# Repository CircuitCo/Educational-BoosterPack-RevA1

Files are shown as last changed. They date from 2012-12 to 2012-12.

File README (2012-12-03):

The Educational BoosterPack is an add-on board for the MSP430 Value Line LaunchPad development kit. This BoosterPack will help new users familiar with the MSP430 LaunchPad by interacting with simple electronic components like LEDs (red/green/blue and white), analog potentiometer, microphone, and speaker. Users will also be able to create more exciting projects with the onboard analog accelerometer and 2x16 character LCD.

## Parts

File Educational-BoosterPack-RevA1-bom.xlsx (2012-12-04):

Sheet: EDUCATIONALBOOSTERPACK
EDUCATIONAL BOOSTERPACK |  |  |  | Revised: | 2012-12-03
BP-EDUC-01 Revision: A1
ITM | QTY | REF DESIGNATOR | PART | PCB FOOTPRINT | DESCRIPTION | MANU | MANU P/N | VENDOR | VENFOR P/N
1 | 5 | C3,C6,C7,C8,C9 | 0.1uF | 402 | CAP CER 0.1UF 10V 10% X5R 0402 | TAIYO | LMK105BJ104KV-F | DK | 587-1227-1-ND
2 | 3 | C4,C11,C12 | 1uF | 402 | CAP CER 1UF 6.3V 10% X5R 0402 | TAIYO | JMK105BJ105KV-F | DK | 587-1231-1-ND
3 | 1 | C5 | 10nF | 402 | CAP CER 10000PF 16V 10% X7R 0402 | YAGEO | CC0402KRX7R7BB103 | DK | 311-1042-1-ND
4 | 1 | C10 | 4.7uF | 603 | CAP CER 4.7UF 6.3V 20% X5R 0603 | MURATA | GRM188R60J475ME19D | DK | 490-5421-1-ND
5 | 1 | D4 | SMW-CL25 | LED603 | LED CHIPLED INGAN WHT TOP SMD | AVAGO | HSMW-CL25 | DK | 516-2278-1-ND
6 | 1 | D6 | CLV6A-FKB | TRICOLOR | LED RED/GREEN/BLUE PLCC6 SMD | CREE | CLV6A-FKB-CK1P1G1BB7R3R3 | DK | CLV6A-FKB-CK1P1G1BB7R3R3CT-ND
7 | 2 | J1,J2 | 1X10 | HEADER1X10 | CONN HEADER FMALE 10POS .1" GOLD | SULLINS | PPPC101LFBN-RC | DK | S7043-ND
8 | 0 | J3,J4 | 1X10,DNI | HEADER1X10 | CONN HEADER FMALE 10POS .1" GOLD | SULLINS | PPPC101LFBN-RC | DK | S7043-ND
9 | 2 | J5,J6 | 1X03 | HEADER1X03 | CONN HEADER .100 SINGL STR 3POS | SULLINS | PEC03SAAN | DK | S1012E-03-ND
10 | 1 | LCD1 | NHD-C0216CZ | LCD | LCD COG CHAR 2X16 WHT TRANSFL | NEWHAVEN | NHD-C0216CZ-FSW-FBW-3V3 | DK | NHD-C0216CZ-FSW-FBW-3V3-ND
11 | 1 | MIC1 | CMC-5042PF-AC | MIC | MIC COND ANALOG OMNI -42DB | CUI | CMC-5042PF-AC | DK | 102-1724-ND
12 | 2 | MK1,MK2 | GATOR | GATOR | GATOR HOLES | N/A | N/A | N/A | N/A
13 | 1 | Q1 | BSS138 | SOT23-3 | MOSFET N-CH 50V 200MA SOT23-3 | DIODES | BSS138-7-F | DK | BSS138-FDICT-ND
14 | 1 | R1 | 33 | 402 | RES 33 OHM 1/16W 5% 0402 SMD | YAGEO | RC0402JR-0733RL | DK | 311-33JRCT-ND
15 | 2 | R2,R9 | 2.2K | 402 | RES 2.2K OHM 1/16W 5% 0402 SMD | VISHAY | CRCW04022K20JNED | DK | 541-2.2KJCT-ND
16 | 1 | R5 | 150 | 402 | RES 150 OHM 1/16W 5% 0402 SMD | YAGEO | RC0402JR-07150RL | DK | 311-150JRCT-ND
17 | 2 | R6,R7 | 100 | 402 | RES 100 OHM 1/16W 5% 0402 SMD | YAGEO | RC0402JR-07100RL | DK | 311-100JRCT-ND
18 | 1 | R8 | 180R, 5% | 402 | RES 180 OHM 1/16W 5% 0402 SMD | YAGEO | RC0402JR-07180RL | DK | 311-180JRCT-ND
19 | 1 | R10 | 100K | 402 | RES 100K OHM 1/16W 5% 0402 SMD | VISHAY | CRCW0402100KJNED | DK | 541-100KJCT-ND
20 | 1 | R11 | 47K | 402 | RES 47K OHM 1/16W 5% 0402 SMD | VISHAY | CRCW040247K0JNED | DK | 541-47KJCT-ND
21 | 1 | R12 | 15R, 0603 | 603 | RES 15 OHM .25W 5% 0603 SMD | VISHAY | CRCW060315R0JNEAHP | DK | CRCW060315R0JNEAHPCT-ND
22 | 2 | R14,R19 | 10K | 402 | RES 10K OHM 1/16W 5% 0402 SMD | VISHAY | CRCW040210K0JNED | DK | 541-10KJCT-ND
23 | 1 | R15 | 1K,0603 | 603 | RES 1.0K OHM 1/10W 5% 0603 SMD | VISHAY | CRCW06031K00JNEA | DK | 541-1.0KGCT-ND
24 | 1 | R17 | 22M,0603 | 603 | RES 22M OHM 1/10W 10% 0603 SMD | PANASONIC | ERJ-3GEYK226V | DK | P22MGCT-ND
25 | 2 | SH1,SH2 | SHUNT | SHUNT | CONN JUMPER SHORTING GOLD FLASH | SULLINS | SPC02SYAN | DK | S9001-ND
26 | 1 | SPKR1 | BUZZER | BUZZER | BUZZER 2.048KHZ 12MM PC MOUNT | CUI | CEM-1203(42) | DK | 102-1153-ND
27 | 1 | TP1 | TESTPOINT | TP | TESTPOINT HOLE | N/A | N/A | N/A | N/A
28 | 1 | U1 | ADXL335 | 16LFCSP | IC ACCELEROMETER 3AXL 3G 16LFCSP | ANALOG | ADXL335BCPZ-RL7 | DK | ADXL335BCPZ-RL7CT-ND
29 | 1 | VR1 | 10K,20% | POT | POT 10K OHM THUMBWHEEL CERM ST | BOURNS | 3352T-1-103LF | DK | 3352T-103LF-ND
30 | 1 | PCB

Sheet: CHANGES
DATE | REV | CHANGES
2012-11-19 | A1 | CHANGE P/N FOR VR1 FROM SM-43 TO 3352T-1-103LF
 |  | REMOVE D5
 |  | REMOVE R13
 |  | CHANGE R9 VALUE FROM 4.7K TO 2.2K
 |  | REMOVE D1, D2, D3
 |  | ADD D6
 |  | ADD R15
 |  | ADD MK1
2012-11-20 |  | ADD MK2
 |  | ADD TP1
 |  | ADD R17
 |  | ADD J5,J6
 |  | ADD R19
 |  | CHANGE R14 VALUE

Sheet: ASSY INSTRUCTIONS
USE SHUNT JUMPERS TO CONNECT J5.1-J5.2 AND J6.1-J6.2

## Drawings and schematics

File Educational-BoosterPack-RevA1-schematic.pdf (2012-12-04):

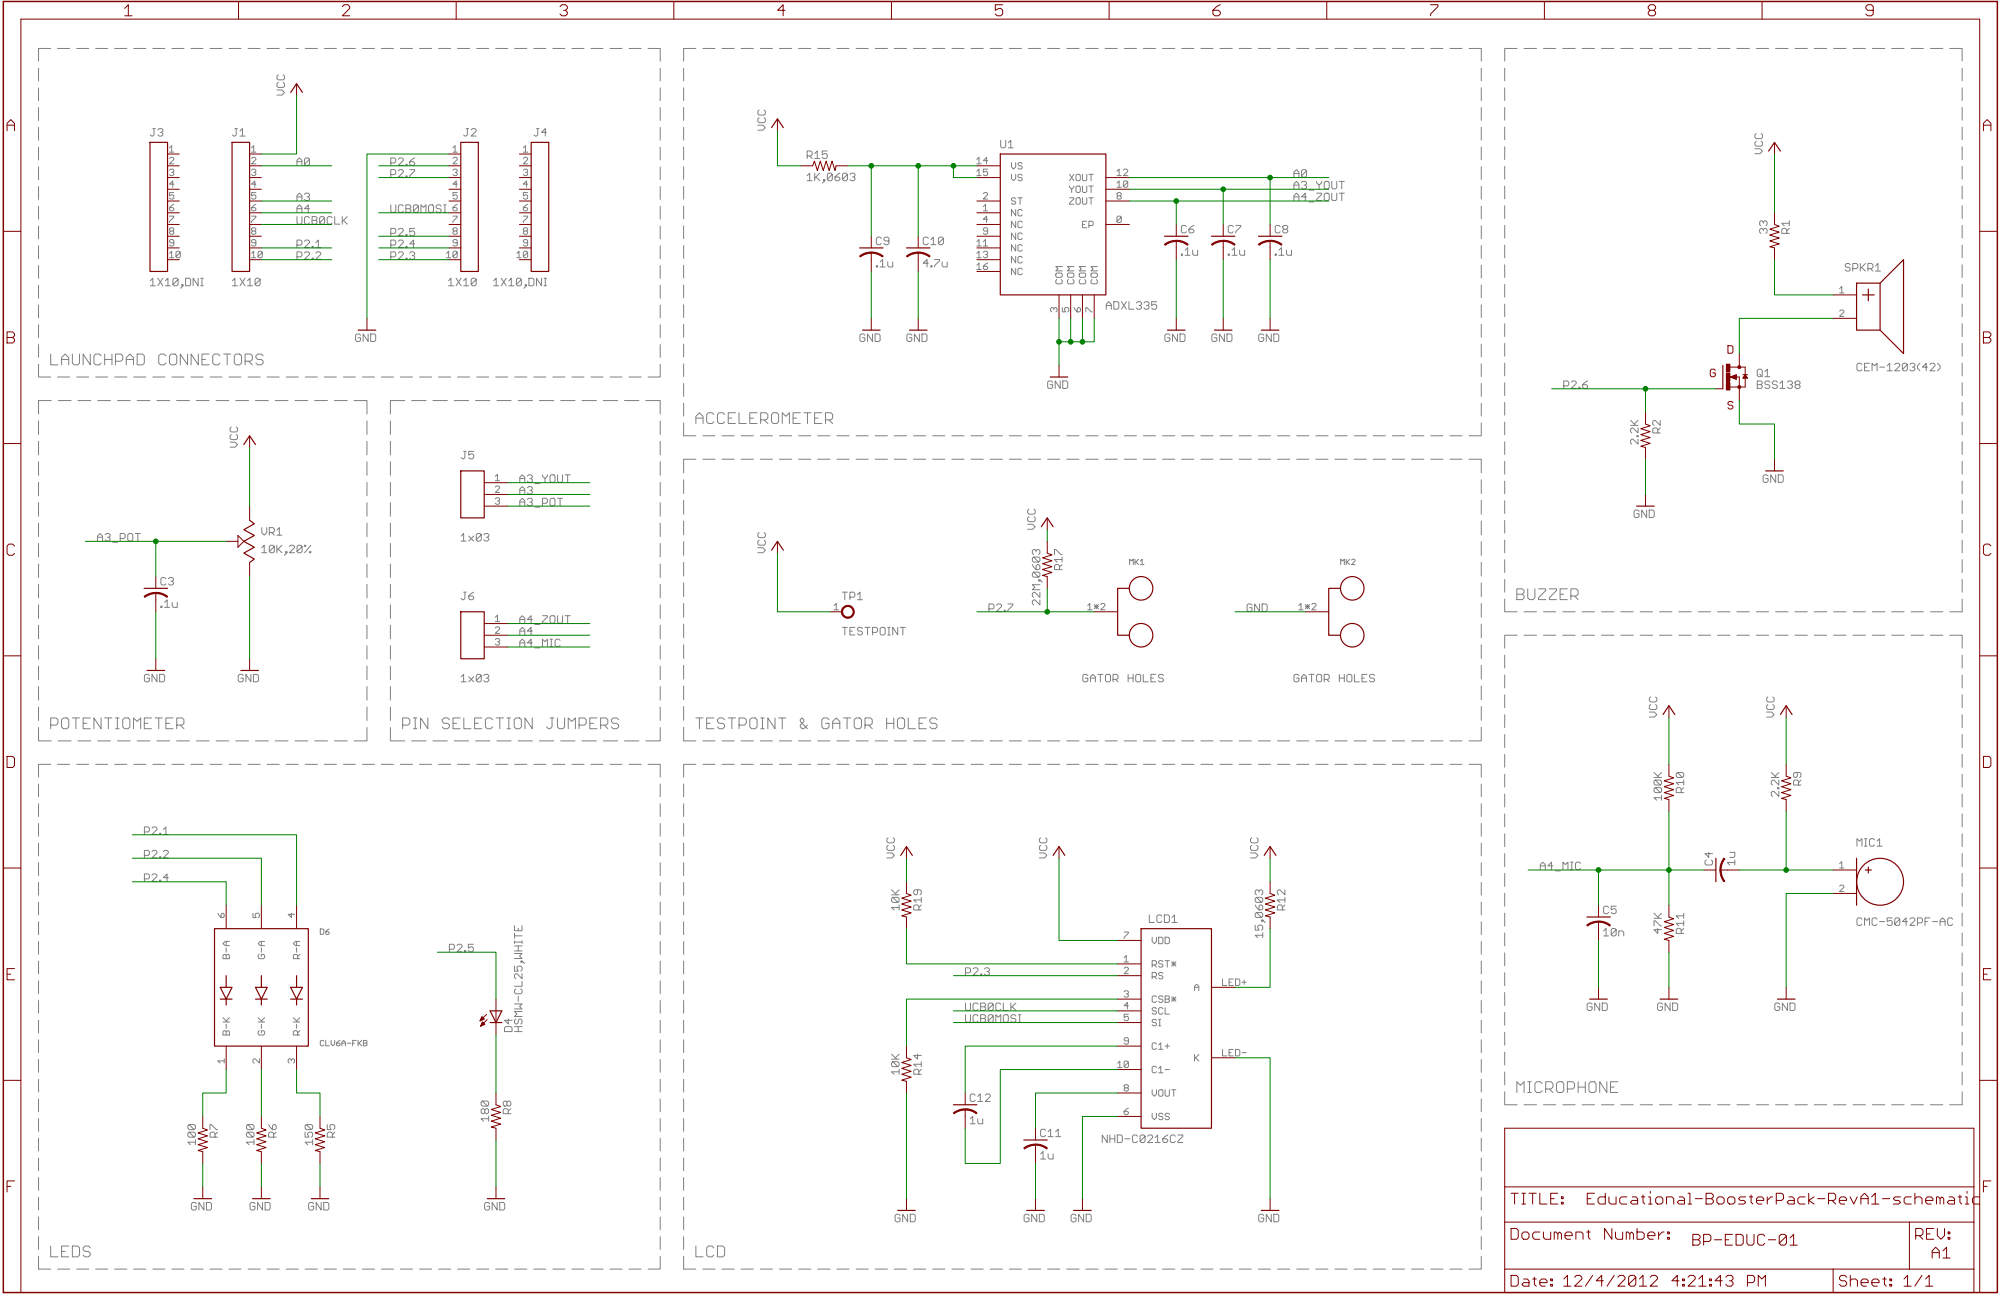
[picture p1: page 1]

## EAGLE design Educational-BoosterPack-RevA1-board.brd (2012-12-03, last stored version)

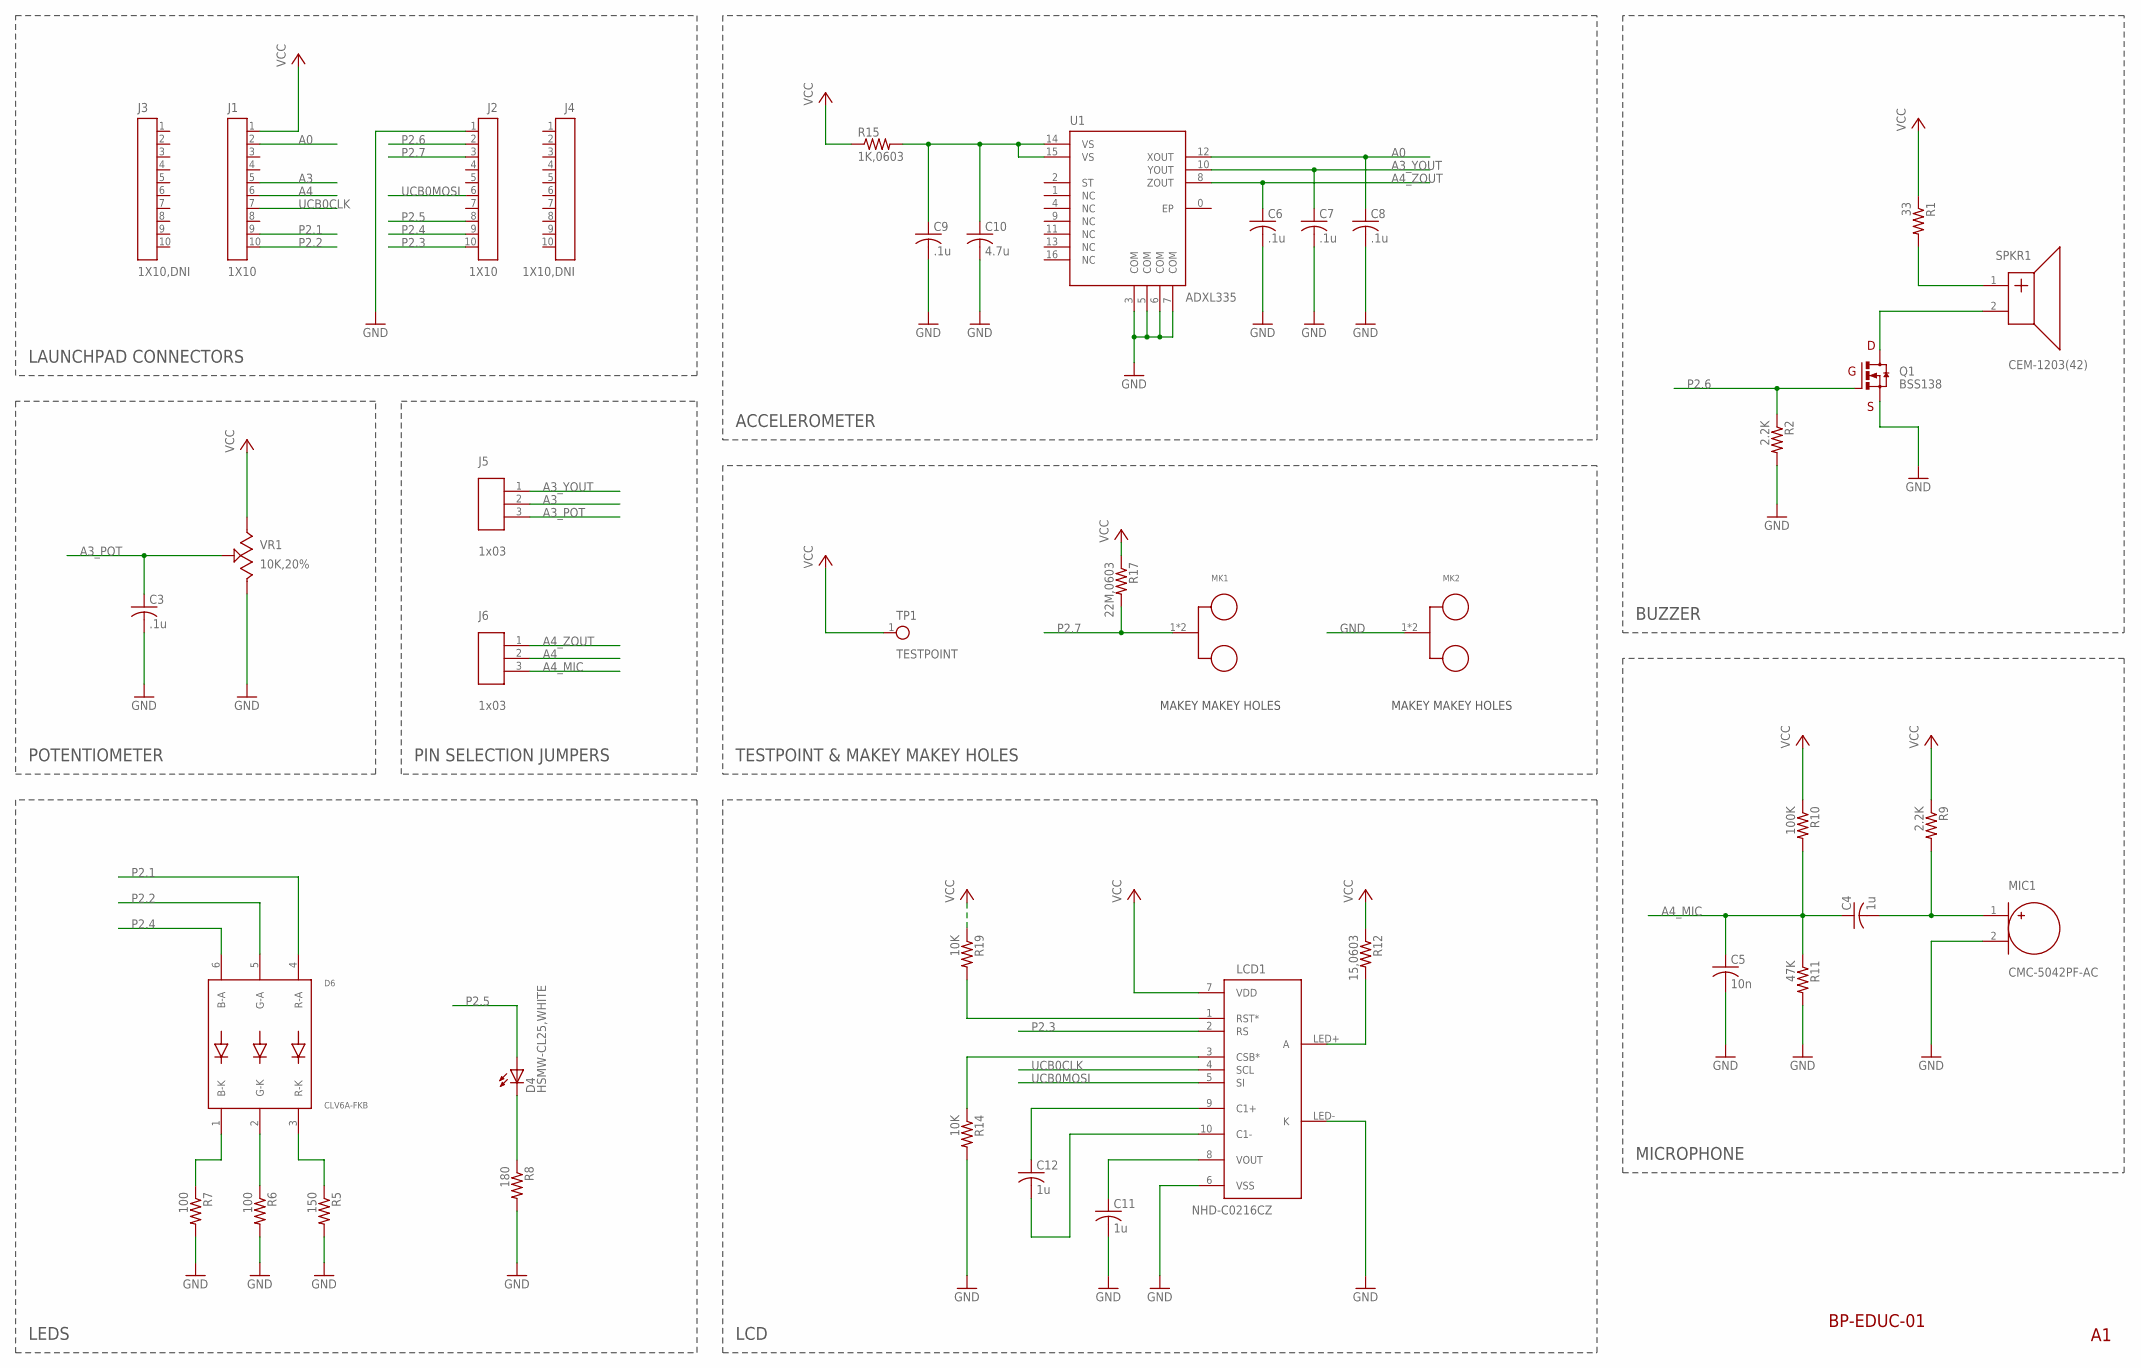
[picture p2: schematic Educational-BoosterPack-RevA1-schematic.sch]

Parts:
C3, C6, C7, C8, C9: .1u; C0402
C4, C11, C12: 1u; C0402
C5: 10n; C0402
C10: 4.7u; C0603
D4: HSMW-CL25,WHITE; CHIPLED_0603
D6: CLV6A-FKB; TRICOLOR-LED6
J1, J2: 1X10
J3, J4: 1X10,DNI; 1X10
J5, J6: 1x03; 1X03
LCD1: NHD-C0216CZ; GENERIC-LCD10-2
MIC1: CMC-5042PF-AC; GENERIC-2PADS2
MK1, MK2: MAKEYMAKEY
Q1: BSS138; SOT23-3
R1: 33; R0402
R2, R9: 2.2K; R0402
R5: 150; R0402
R6, R7: 100; R0402
R8: 180; R0402
R10: 100K; R0402
R11: 47K; R0402
R12: 15,0603; R0603
R14, R19: 10K; R0402
R15: 1K,0603; R0603
R17: 22M,0603; R0603
SPKR1: CEM-1203(42); GENERIC-2PADS
TP1: TESTPOINT
U1: ADXL335; LFCSP-16
VR1: 10K,20%; GENERIC-3HOLES

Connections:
A0: C8.1, J1.2, U1.12 (XOUT)
A3: J1.5, J5.2
A3_POT: C3.1, J5.3, VR1.2
A3_YOUT: C7.1, J5.1, U1.10 (YOUT)
A4: J1.6, J6.2
A4_MIC: C4.1, C5.1, J6.3, R10.2, R11.1
A4_ZOUT: C6.1, J6.1, U1.8 (ZOUT)
GND: C3.2, C5.2, C6.2, C7.2, C8.2, C9.2, C10.2, C11.2, J2.1, LCD1.6 (VSS), LCD1.LED- (K), MIC1.2 (MIC_N), MK2.1, MK2.2, Q1.2 (S), R2.2, R5.2, R6.2, R7.2, R8.2, R11.2, R14.2, U1.3 (COM), U1.5 (COM), U1.6 (COM), U1.7 (COM), VR1.3
unnamed: C9.1, C10.1, R15.2, U1.14 (VS), U1.15 (VS)
unnamed: C4.2, MIC1.1 (MIC_P), R9.2
unnamed: LCD1.LED+ (A), R12.2
unnamed: D6.2 (G-K), R6.1
unnamed: R1.2, SPKR1.1 (SPKR_P)
unnamed: Q1.3 (D), SPKR1.2 (SPKR_N)
unnamed: LCD1.3 (CSB*), R14.1
unnamed: D6.3 (R-K), R5.1
unnamed: D6.1 (B-K), R7.1
unnamed: C11.1, LCD1.8 (VOUT)
unnamed: C12.2, LCD1.10 (C1-)
unnamed: C12.1, LCD1.9 (C1+)
unnamed: LCD1.1 (RST*), R19.2
unnamed: D4.C, R8.1
P2.1: D6.4 (R-A), J1.9
P2.2: D6.5 (G-A), J1.10
P2.3: J2.10, LCD1.2 (RS)
P2.4: D6.6 (B-A), J2.9
P2.5: D4.A, J2.8
P2.6: J2.2, Q1.1 (G), R2.1
P2.7: J2.3, MK1.1, MK1.2, R17.2
UCB0CLK: J1.7, LCD1.4 (SCL)
UCB0MOSI: J2.6, LCD1.5 (SI)
VCC: J1.1, LCD1.7 (VDD), R1.1, R9.1, R10.1, R12.1, R15.1, R17.1, R19.1, TP1.1, VR1.1

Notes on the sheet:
MAKEY MAKEY HOLES
LAUNCHPAD CONNECTORS
POTENTIOMETER
ACCELEROMETER
BUZZER
MICROPHONE
LCD
LEDS
TESTPOINT & MAKEY MAKEY HOLES
PIN SELECTION JUMPERS
BP-EDUC-01

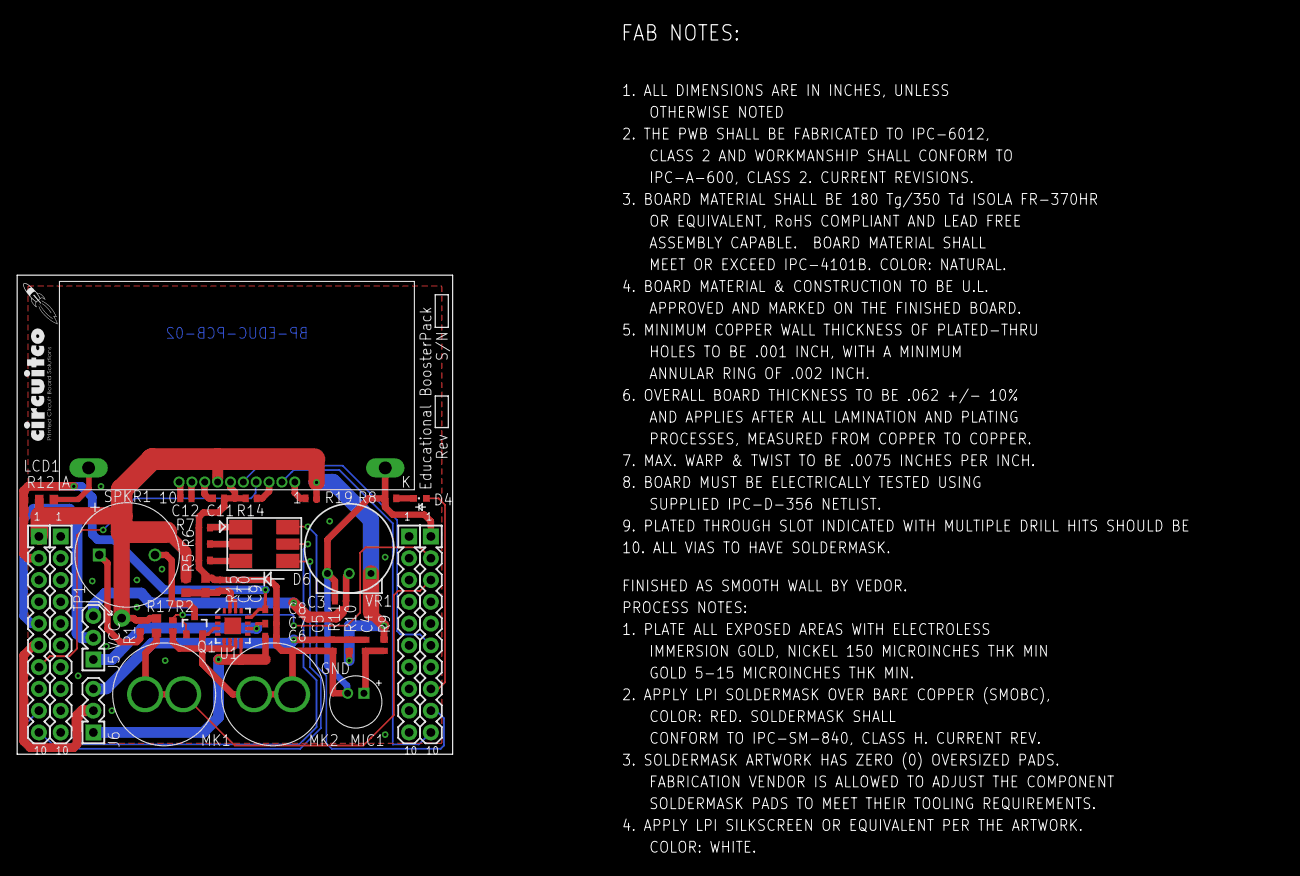
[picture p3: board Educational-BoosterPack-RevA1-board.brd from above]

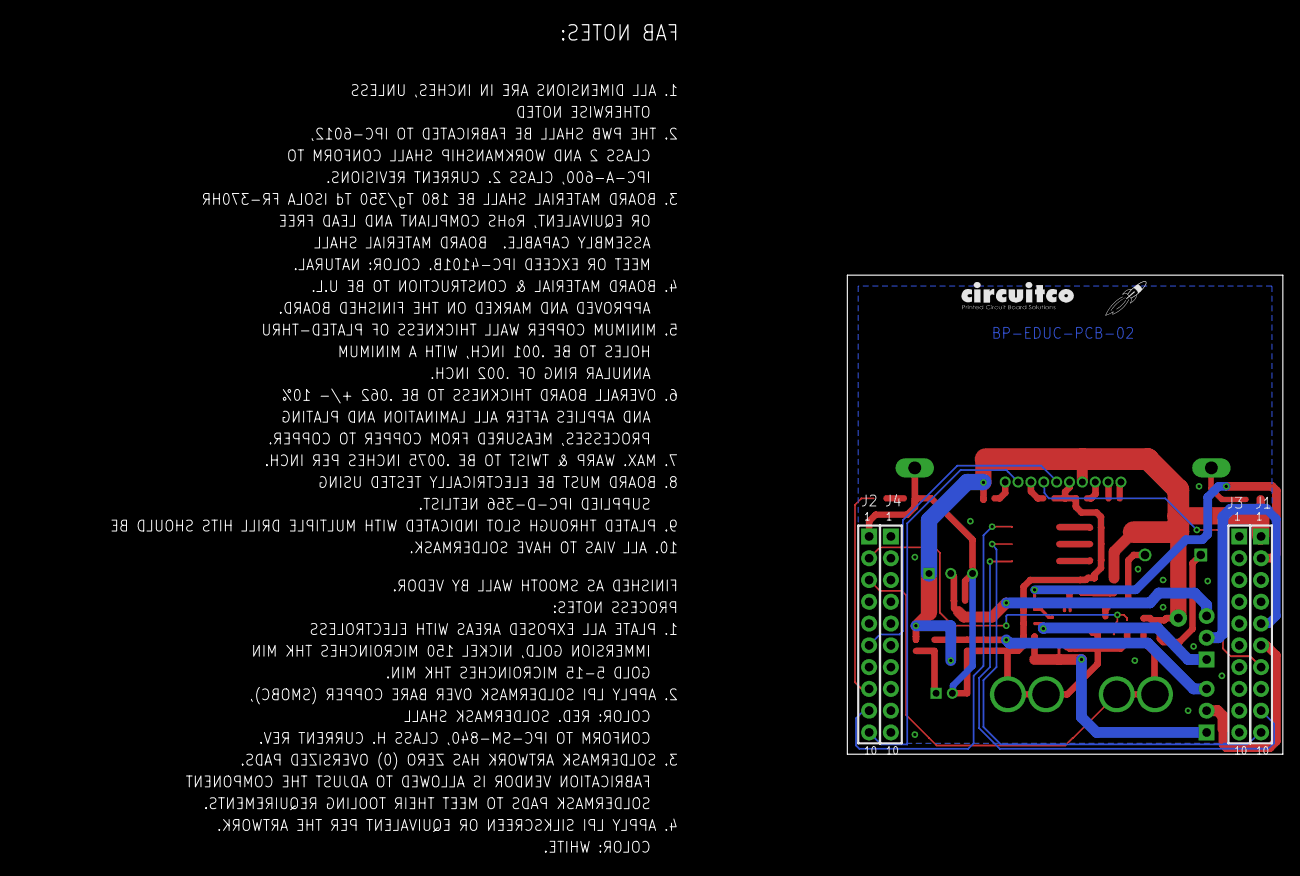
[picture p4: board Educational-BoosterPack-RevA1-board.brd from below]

Board: 2 copper layers, 50.8 x 55.9 mm, 45 parts (2 on the bottom side), 32 nets.

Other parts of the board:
E$1, E$3: LOGO-CIRCUITCO
E$2, E$4: LOGO-ROCKET

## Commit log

2012-12-03 rm brd ger
    [Educational-BoosterPack-RevA1-board.brd]
2012-12-03 rm sch
    [Educational-BoosterPack-RevA1-schematic.sch]
2012-12-04 rm MK
    [Educational-BoosterPack-RevA1-bom.xlsx]
2012-12-04 add gator
    [Educational-BoosterPack-RevA1-bom.xlsx]
